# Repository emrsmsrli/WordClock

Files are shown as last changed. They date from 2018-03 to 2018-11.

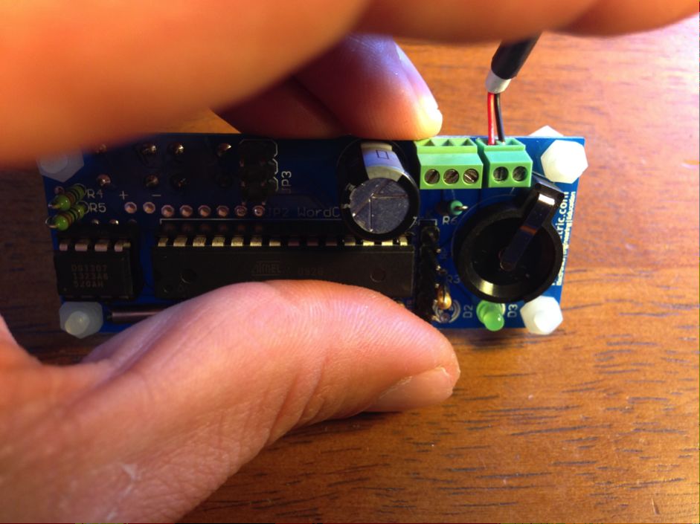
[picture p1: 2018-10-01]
etc/img/circuit/16.jpg

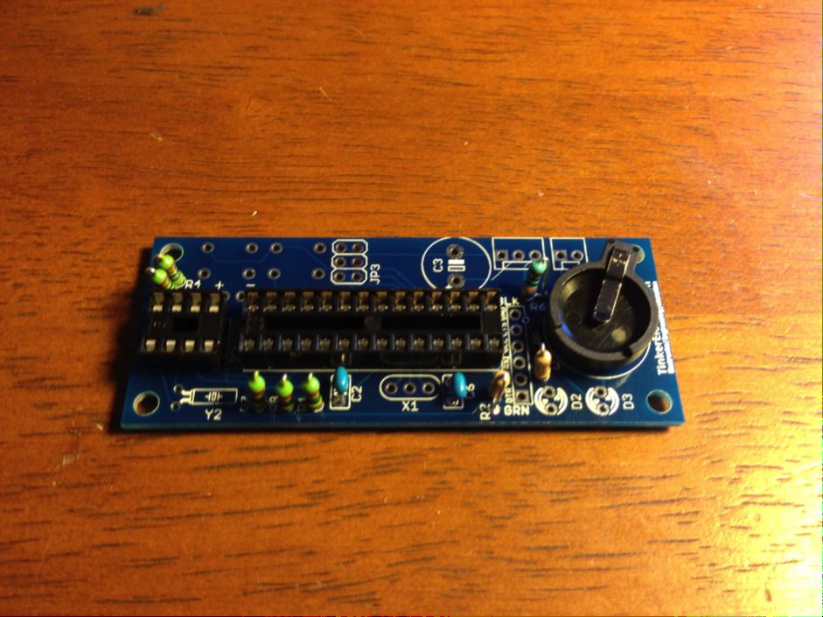
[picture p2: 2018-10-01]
etc/img/circuit/2.jpg

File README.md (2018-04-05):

# WORD CLOCK ARDUINO

The code in this repository is a heavily modified version of 
[Tinker's Word Clock code](http://www.instructables.com/id/Tinkers-Word-Clock-REVISITED-NOW-110-More-AWESOME-/). 
And uses a modified version of [OneButton](https://github.com/mathertel/OneButton) library.

## TODO
- [x] Add second support alongside of minutes and hours
- [x] Make the leds fade-in and -out when a change in time or color happens
- [x] Use external interrupts to count button clicks so we can increment both hour and minute with a single button
- [x] Implement smoothstep interpolation to led animations
- [x] Implement night mode, where overall led intensity is 0.125 instead of 1.0
- [x] Implement happy birthday mode
- [x] Add documentation

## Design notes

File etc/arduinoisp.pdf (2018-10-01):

Arduino Uno as an ISP programmer

Programming a Target AVR using Arduino Uno board loaded with

ArduinoISP

(April 21, 2015, author: B. Lazar) Arduino Uno + ArduinoISP form an ordinary ISP programmer that is used by avrdude to program various 8 bit AVRs with any kind of hex file. No bootloader is needed, no hardware removal from Arduino Uno is necessary

It may happen that you have an Arduino Uno that you bought, played a bit with it and now you want to move further, to build your own board, which can be just a simple AVR microcontroller + an oscillator + a LED, but you do not have an ISP programmer.

In reality, Arduino Uno is everything you need to program a large variety of AVRs. You just have to follow the four steps described below:
1) Open Arduino 1.0.1 and upload ArduinoISP to Arduino Uno.
2) Connect the ISP pins of Arduino Uno to the Target AVR as indicated in the Fig.1.
3) Write your source code, compile it and generate the hex file.
4) Use avrdude command lines to upload the hex file into the Target AVR.

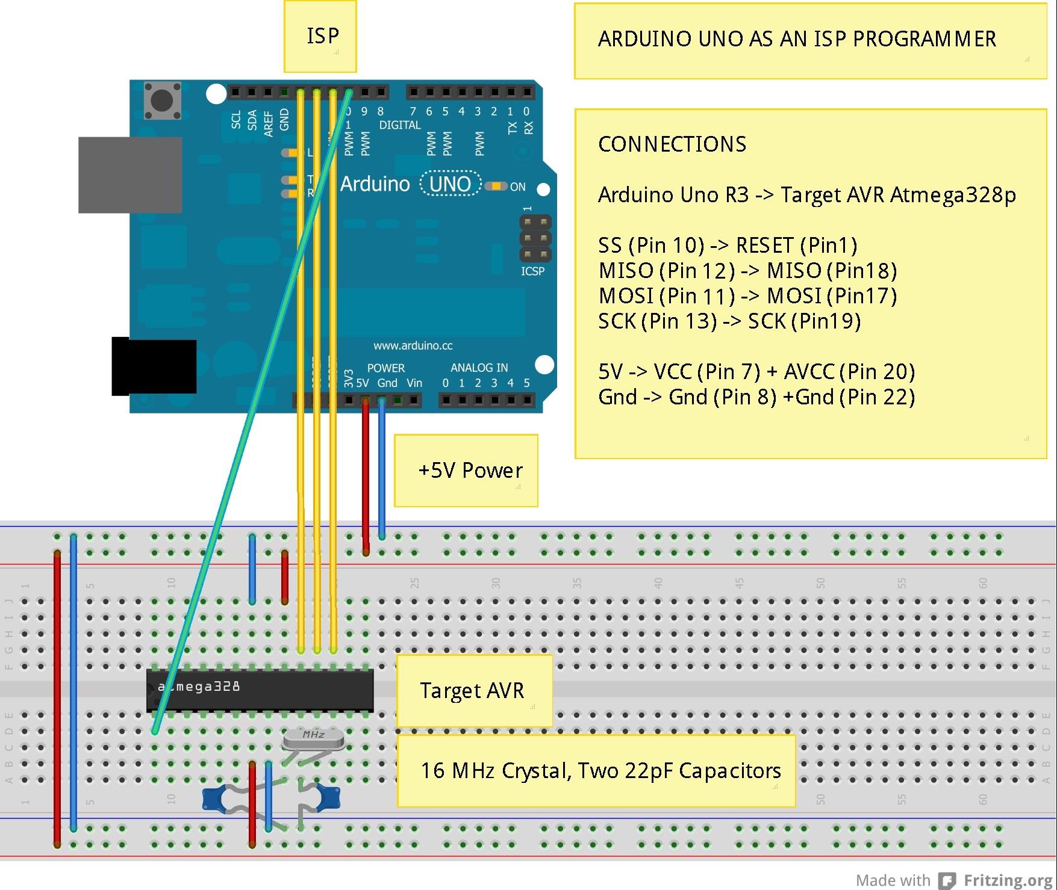
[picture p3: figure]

Fig. 1

Each of the four steps explained in detail:

(1) Open Arduino 1.0.1 and upload ArduinoISP to Arduino Uno
Start Arduino 1.0.1, go to Files->Examples and open ArduinoISP. Then from Tools->Board select Arduino Uno, from Tools->Programmer select AVR ISP or Arduino as ISP. Access Tools->Serial Port and write down the name of the port (ex. COM3) which is needed for avrdude.

Finally, press Files->Upload to load ArduinoISP to Arduino Uno. This operation transforms Arduino Uno into an ISP programmer.

(2) Connect the ISP pins of Arduino Uno to the Target AVR as indicated in Fig.1
It is extremely important to make sure that the ISP pins of Arduino Uno are connected to the Target AVR like this:
Arduino Uno | Target AVR (ex. Atmega328p)
SS | RESET
MOSI | MOSI
MISO | MISO
SCK | SCK

Frequent wiring mistakes are Arduino Uno(SS) -> Target AVR(SS) and Arduino Uno(RESET) -> Target AVR(RESET).

As a note: The crystal and its two capacitors have to be as close to XTAL1, XTAL2 pins of the Target AVR as possible (like in Fig. 1). If you position them in a different configuration, far from the processor, running wires between capacitors, crystal and the AVR, the newly formed oscillator can refuse to work and avrdude will throw the error “Invalid device signature” when you try to program the microcontroller.

(3) Write your source code, compile it and generate the hex file
In Arduino 1.0.1->Files->Preferences check Show verbose output during compilation. This will display a lot of information, when the code is compiled, including the location of the hex file.

Go to File->Examples->01.Basics and load Blink example. This will be considered as your source code.

Go to Sketch menu and press Verify/Compile.

When the compilation completes search in the lower side of the screen the path of the generated Blink hex file. It looks like this one:

C:\Users\Victor\AppData\Local\Temp\build1325897986179133197.tmp\Blink.cpp.hex

Select it with the mouse and press Ctrl-C followed by a Paste in Notepad, for instance. You will need the path for avrdude.

REMARK: The hex file can be generated with any IDE you like, not necessarily using Arduino 1.0.1. You can write your code in: BASCOM, CodeVision, AVR Studio, IAR which, in most cases, are far better choices than Arduino 1.0.1.

ATTENTION! If you use Arduino 1.0.1 to generate a hex file, you have to select the right board/processor from Tools->Board. For example, you simply can not compile the Blink Led code for Arduino Uno

(Atmega328p) and expect it to work on a target Atmega32 microcontroller. Also, even if, your target chip on the breadboard is an Atmega328p DIL28, you have to take into account that pin 13 of Arduino Uno (the one that drives the led) corresponds to pin 19 (SCK) on your target Atmega328p microcontroller.
AS A CONCLUSION: Arduino 1.0.1 works well for compiling code written for the boards in its list.
For anything else, different boards or stand alone AVRs, it is highly indicated to use a general purpose IDE, not Arduino 1.0.1.
(4) Use avrdude command lines to upload the hex file into the Target AVR
Avrdude comes bundled with WinAVR, a software that is free and can be found on the internet.
Locate avrdude inside WinAVR, start the Windows standard application Command Prompt and launch avrdude from within Command Prompt.
A better choice would be to use a software, similar to Command Prompt but much easy to use, called PowerCmd because it allows you to save and copy-paste the long avrdude command lines, with many options and complicated paths to hex files, necessary to program an AVR (see the example).

At this moment, it is supposed that Arduino Uno is already loaded with ArduinoISP, connected to the PC with an USB cable and all wires, between the Target AVR and Arduino Uno acting as an ISP programmer, are in their place as in Fig. 1.

For the example that follows, the Target AVR is chosen to be an Atmega328p already set to run at 16 MHz.

EXAMPLE:

Launch PowerCmd (or Command Prompt) and copy this line:

c:\>avrdude -P COM3 -b 19200 -c avrisp -p m328p –n

in one of its command windows.

If your AVR is different then change the option -p m328p to -p … corresponding to your microcontroller. Most likely you do not have to modify the other options. (Note: The command c:\>avrdude -? will display a list with explanations regarding the meaning of the switches: –P, -b, -c, -p, -n and many others.)

Press Enter.

Avrdude should display the message:

c:\>avrdude -P COM3 -b 19200 -c avrisp -p m328p -n
avrdude: AVR device initialized and ready to accept instructions
Reading | ################################################## | 100% 0.14s
avrdude: Device signature = 0x1e950f
avrdude: safemode: Fuses OK
avrdude done. Thank you.

telling you that the Target AVR is accessible and can be programmed. (-n option instructs avrdude to make no modification inside the Target AVR).

You can program now the Target AVR with the Blink.cpp.hex file, generated at point (3), by copying the avrdude command, highlighted in red (see below), in PowerCmd and pressing Enter.
Do not forget to change the path to the hex file (the string of characters between “”) according to the settings in your computer. The rest of the command line, including the final “:i” will likely remain unchanged.

c:\>avrdude -P COM3 -b 19200 -c avrisp -p m328p -u -U flash:w:"C:\Users\Victor\AppData\Local\Temp\build1325897986179133197.tmp\Blink. cpp.hex":i

avrdude: AVR device initialized and ready to accept instructions

Reading | ################################################## | 100% 0.16s

avrdude: Device signature = 0x1e950f
avrdude: NOTE: FLASH memory has been specified, an erase cycle will be performed To disable this feature, specify the -D option. avrdude: erasing chip
avrdude: reading input file "C:\Users\Victor\AppData\Local\Temp\build1325897986179133197.tmp\Blink.cpp.hex" avrdude: writing flash (1084 bytes):
Writing | ################################################## | 100% 1.76s

avrdude: 1084 bytes of flash written
avrdude: verifying flash memory against C:\Users\Victor\AppData\Local\Temp\build1325897986179133197.tmp\Blink.cpp.hex: avrdude: load data flash data from input file C:\Users\Victor\AppData\Local\Temp\build1325897986179133197.tmp\Blink.cpp.hex: avrdude: input file
C:\Users\Victor\AppData\Local\Temp\build1325897986179133197.tmp\Blink.cpp.hex contains 1084 bytes
avrdude: reading on-chip flash data:
Reading | ################################################## | 100% 1.31s

avrdude: verifying ...
avrdude: 1084 bytes of flash verified

avrdude done. Thank you.

Success! At this moment your Target AVR is programmed and ready to execute the code.

Most common errors you may get from avrdude:

1) c:\>avrdude -P COM3 -b 19200 -c avrisp -p m328p -n
avrdude: ser_open(): can't open device "\\.\COM3": The system cannot find the file specified.

Reason: The USB connection between the PC and Arduino Uno is not good. If the connection is good but the error still keeps coming press the Reset button of Arduino Uno.

2) c:\>avrdude -P COM3 -b 19200 -c avrisp -p m328p -n
avrdude: ser_open(): can't open device "\\.\COM3": Access is denied.

Reason: Another application that uses COM3 port, likely a Serial Monitor, is running. Close it.

3) c:\>c:\>avrdude -P COM3 -b 19200 -c avrisp -p m328p -n
Access is denied.

Reason: c drive appears twice: “c:\>c:\>”.

4) c:\>avrdude -P COM3 -b 19200 -c avrisp -p m328p -n
avrdude: stk500_program_enable(): protocol error, expect=0x14, resp=0x50 avrdude: initialization failed, rc=-1
Double check connections and try again, or use -F to override this check.
avrdude: stk500_disable(): protocol error, expect=0x14, resp=0x51 avrdude done. Thank you.

Reason: The Target AVR is not powered or does not exist.
This message is also useful for testing, before connecting any Target AVR, that Arduino Uno + ArduinoISP work as an ISP programmer and the connection to the PC is proper.
5) c:\>avrdude -P COM3 -b 19200 -c avrisp -p m328p -n
avrdude: stk500_getsync(): not in sync: resp=0xf0
avrdude done. Thank you.

Reason: Arduino Uno needs a Reset.

6) c:\>avrdude -P COM3 -b 19200 -c avrisp -p m328p -n
avrdude: AVR device initialized and ready to accept instructions
Reading | ################################################## | 100% 0.14s
avrdude: Device signature = 0xffffff (Device signature = 0x000000)
avrdude: Yikes! Invalid device signature.
Double check connections and try again, or use -F to override this check.

Reasons:
a) ISP connections (SS, MOSI, MISO, SCK) -> (RESET, MOSI, MISO, SCK), between Arduino Uno and the Target AVR, are not good, wrong wiring.
b) The AVR oscillator (external) does not work.

List of commonly used AVRs and how they should be connected to an Arduino

Uno, for programming

If you do not use an Atmega328p target then you should adapt the wiring in Fig. 1 according to your specific target AVR (ex. Attiny13, 84, 85, Atmega8, etc.).

Attiny13 | Uno -> pin Attiny13

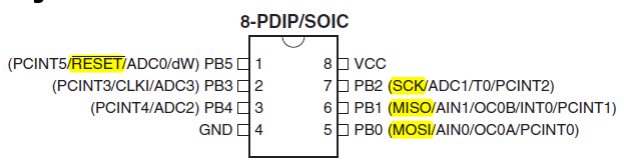
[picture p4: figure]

| SS -> 1 MOSI -> 5 MISO -> 6 SCK -> 7

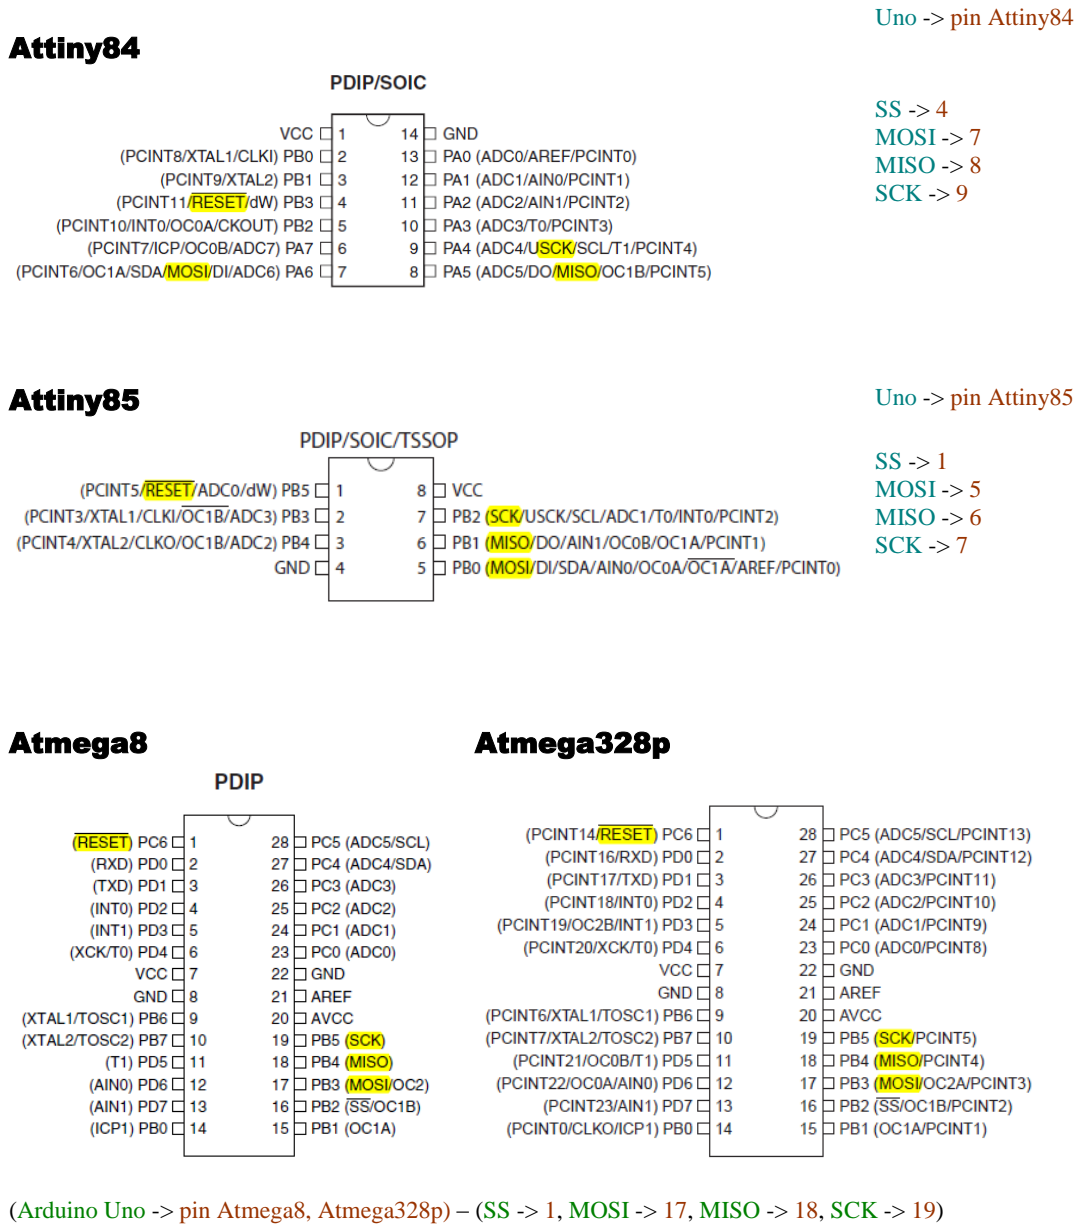
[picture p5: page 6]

Attiny84 | Uno -> pin Attiny84
| SS -> 4 MOSI -> 7 MISO -> 8 SCK -> 9
Attiny85 | Uno -> pin Attiny85
| SS -> 1 MOSI -> 5 MISO -> 6 SCK -> 7

Atmega8

Atmega328p

(Arduino Uno -> pin Atmega8, Atmega328p) – (SS -> 1, MOSI -> 17, MISO -> 18, SCK -> 19)

Atmega32U4

Uno

>Atmega32U4

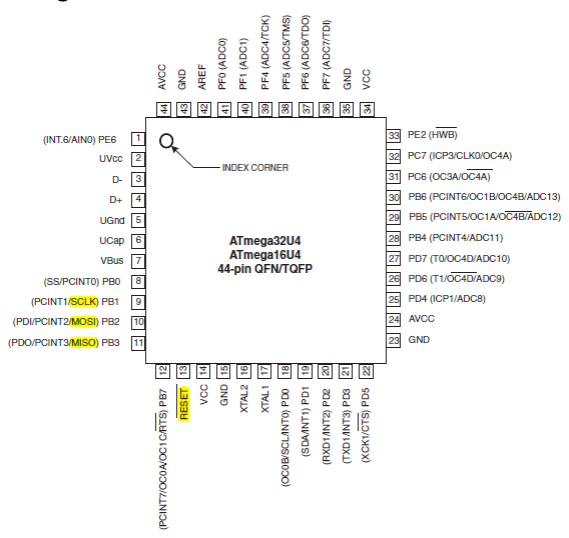
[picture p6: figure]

SS

->

1

3
MOSI

-> 10
MISO

-> 11
SCK

->

9

Atmega32 | Uno -> pin Atmega32

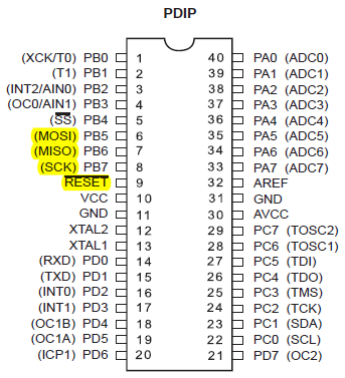
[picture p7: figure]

| SS -> 9 MOSI -> 6 MISO -> 7 SCK -> 8

Last update: July 3, 2016.

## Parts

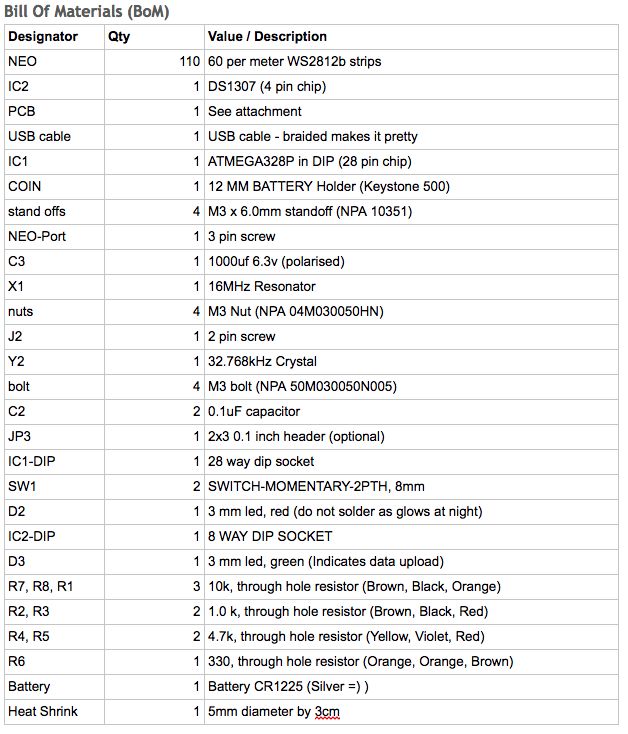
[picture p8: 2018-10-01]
etc/materials.jpg

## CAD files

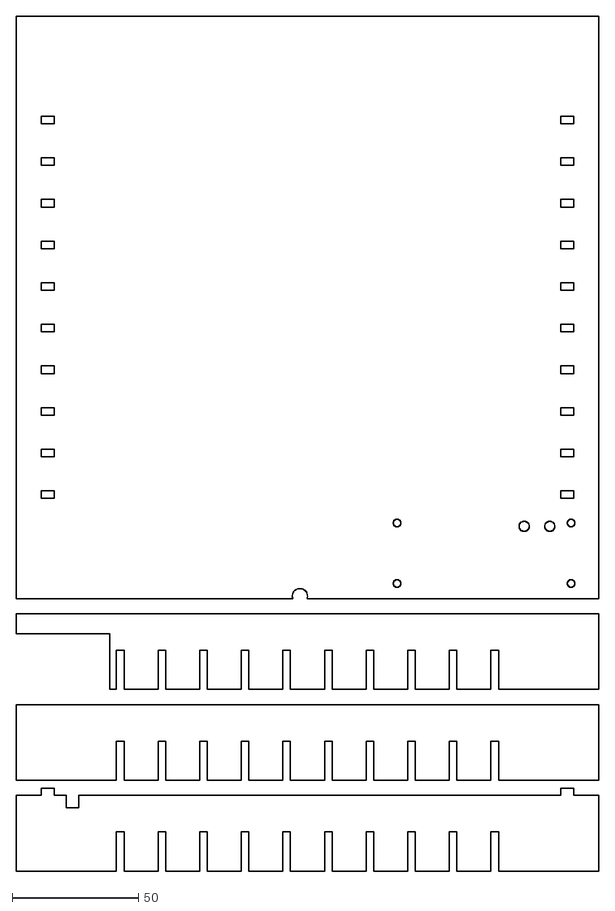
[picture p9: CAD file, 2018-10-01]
etc/backface/final/slat_output_m.dxf
231.0 x 339.0

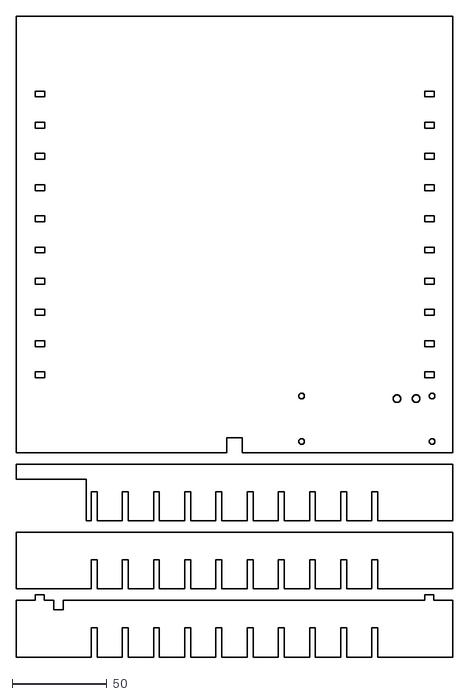
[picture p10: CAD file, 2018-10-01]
etc/backface/slat_output.dxf
231.0 x 339.0

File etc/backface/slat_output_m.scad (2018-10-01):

$fn=50;
materialWidth = 2.9;

numberOfSlots = 10;
spacingOfSlots = 16.5; //Absolute, between centres, this is the LED spacing

cableSlot = 5; // Width/height of cable slot

shortLength = 37;
shortHeight = 22;

slatLength = 231; //Overall length
slatHeight = 30; //Overall height

backPlaneLength = 231;
lockingPinWidth = 5;
lockingPinRafterInset = 10;

slotWidth = materialWidth+0.1; //Slot plus a little for fitting
slotHeight = slatHeight/2+0.5; //height plus a little for fitting


spaceBetweenRepeats = 6; //When you repeat them

shiftBy = (slatLength-((numberOfSlots-1)*spacingOfSlots+slotWidth))/2;


//slatLength/2 -
//        (numberOfSlots*(spacingOfSlots+slotWidth))/2 + spacingOfSlots/2;

// counts: 1, 7, 7, 11

    
for (i = [0:0]){
    translate([0,i*(slatHeight+spaceBetweenRepeats)])
        rafter(cableHole = "yes", lockingPin ="yes");
    }

for (i = [1:1]){
    translate([0,i*(slatHeight+spaceBetweenRepeats)])
        rafter(cableHole = "no", short ="no");
    }

for (i = [2:2]){
    translate([0,i*(slatHeight+spaceBetweenRepeats)])
        rafter(cableHole = "no", short ="yes");
    }


    
for (i = [3:3]){
    translate([0,i*(slatHeight+spaceBetweenRepeats)])
        translate([0,0]){
            backPlate();}
    }    
    
    


module rafter (){
    //one of them
            if(lockingPin=="yes"){
            translate([lockingPinRafterInset,slatHeight]){
                square(size = [lockingPinWidth,materialWidth],center=false);
            }
            translate([slatLength-lockingPinRafterInset-lockingPinWidth,slatHeight]){
                square(size = [lockingPinWidth,materialWidth],center=false);
            }
        }
    difference() {
        square(thickness = materialWidth, size = [slatLength,slatHeight],center=false); //main slat
        if(cableHole=="yes"){
            //power cable
            translate([shiftBy/2
                    ,slatHeight-cableSlot])
            square(size = [cableSlot,cableSlot],center=false);}


            //short
        if(short=="yes"){
            square(size = [shortLength,shortHeight],center=false);}
        

        
        //Move the slots to centre them
        translate([shiftBy
                ,0,0])
            //square(size = [5,5], center = false);
        
           for (i = [0:numberOfSlots-1]){
                translate([i*(spacingOfSlots),0])
                square(size = [slotWidth,slotHeight],center=false); //removed slat
        }
        
    }
}



module backPlate(){
    difference() {
        square(thickness = materialWidth, size = [backPlaneLength,backPlaneLength],center=false); 
        translate([backPlaneLength-80-3,3]){ //indent the pcb from the edge by this much
            circuitBoard();
        }
        translate([backPlaneLength/2 - 6/2,1]){
                circle(3);
                //square(size=[6,6]);
        }
        
        translate([0,((backPlaneLength-((numberOfSlots-1)*spacingOfSlots+slotWidth))/2)]){
            for (i = [0:numberOfSlots-1]){
                translate([0,i*spacingOfSlots]){
                    translate([lockingPinRafterInset+(backPlaneLength-slatLength)/2,0]){ //left side
                        square([lockingPinWidth+0.1,materialWidth+0.1]); //slot for positioning
                    }
                    translate([backPlaneLength-lockingPinWidth-lockingPinRafterInset-(backPlaneLength-slatLength)/2,0]){ //right side
                        square([lockingPinWidth+0.1,materialWidth+0.1]); //slot for positioning
                    
                    }
                }
            }
        }
        
        
    }
}


module circuitBoard(){
            //button 1
            standOffHoleSize = 3/2; //radius
            buttonHoleSize = 4/2;//radius

            translate([75-11.43,25.65]){ //80-18.221,35-28.656
                circle(buttonHoleSize);
            }
            //button 2
            translate([75-21.59,25.65]){ //80-38.481,35-28.656
                circle(buttonHoleSize);
            }
            
            //standoffs x4
             translate([3,3]){
                circle(standOffHoleSize);
            }       
             translate([3,27]){
                circle(standOffHoleSize);
            }  
            translate([72,3]){
                circle(standOffHoleSize);
            }  
            translate([72,27]){
                circle(standOffHoleSize);
            } 

}

module pcbAdapter(){
    difference(){
        circle(6/2);
        circle(4/2);
    }
}

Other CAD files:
etc/backface/slat_output.scad

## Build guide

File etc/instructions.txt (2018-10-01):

Three major components go into building this clock:

The Electrical - this keeps track of the time, changes the colour and makes it glow all pretty. This is made of the ‘PCB’ (Printed Circuit Board), microcontroller and power via USB.
The Mechanical - This is responsible for its structure and preventing the light seeping into other letters. Its mainly made of the ‘baffle’ and a backing plate.
The Face - To get the face done nicely we use a vinyl sticker with frosting. Out of all the methods I’ve found this to work the best. The face is responsible for the letters appearing crisp and readable.
Next, we collect all the parts!

Gather the following parts:

Mechanical:

Acrylic for internal structure - 2mm black opaque acrylic sheet 16.5 inches (420mm) by 28.3 inches (720mm). This will need to be laser cut later. There are a variety of local laser cutting workshops available to do this.
Ikea Ribba frame (9inch / 23cm square), either black or white http://www.ikea.com/us/en/catalog/products/60078034/#/00078032 This will be our outside frame.
Electrical:
The following parts below are needed. Note: the lithium battery is not normally included due to flight restrictions.

Bill Of Materials (BoM) (see attached image)

PCB and Schematic: (see attached images)

-Attached is the Eagle schematic and board. As well as the GERBER files needed to get the board produced at a PCB house.

Face: The face is to be cut out of vinyl adhesive. An additional ‘frosting’ layer is added to diffuse the light. (see attachment)

Code: Code is attached (*.ino) this can be uploaded using the Arduino uploader.
You will need:

Parts:

PCB and all electronic components listed in the Bill of Materials (BoM)
Tools:

Soldering Iron
Safety Glasses
Solder
Side Cutters
Assembling the main Printed Circuit Board (PCB)

Following the BoM, solder each of the components.

It is best to start with the IC holders (IC1-DIP, IC2-DIP). This ensures it is all flat. Note the notch and align to this.
Resistors are the next step. Identify them using the colour band codes listed in the BoM.
Install capacitors C1 and C2
Solder the three pin resonator. There is no polarisation/wrong way of putting this.
Install the 32kHz crystal at Y2. No polarisation. Leave enough leg space for bending.
Optional: Green LED D3 can now be installed. This indicates data transfer when uploading code.
D2 Red LED can be skipped as it might shine through at night time creating an unwanted glow.
Screw terminals can now be installed. Note that the opening must face the outside of the board.
JP3 and the FTDI programming header are optional
C3 Large capacitor has a polarisation. Note the long and short leg, also the white line (opposite side then photographed) The negative (short+white band) goes on the outer edge, the diagram also matches (colored in bar on the silk screen).
The two buttons are to be installed on the back side. This is so they poke through the back holes.
You can now install the ICs. Nore the notch that must line up. In this picture the notches are far left on each.
Now we can add the standoffs
Place the post though the bottom and nut over the top. It works best if you hold the nut and screw the post into it from the under side.
Posts are now complete.
Cut the USB cable on the mini/micro side as we are keeping the large USB plug to power the device.
Pull back the woven braid and expose the wires inside.
Discard the white and green wires as we only need red (positive) and black (negative)
Add heat shrink as to prevent the braid from running away
Connect the power cable to the main PCB as seen here. We are now done with the PCB for now.
Please see the corrections if you have Version 1.2 below
Fixes in Version 1.2

Fix 1: Jumper JP3 pin and switch pin shown below. This corrects power only being routed to a portion of the board. Best to do this after all soldering so the switch is unobstructed.
Fix 2: Note that Version 1.2 incorrectly labeled the Light port. Light strip labeling is as below, looking from the top, Left to Right: Negative (Black), Positive (Red), Data (Yellow)
Attached are the items for laser cutting the baffle and back plate. There is an SCAD model allowing you to change the size of the clock. Also an SVG with one of each item.

After laser cutting the parts you will now have:

10 Full beams
10 Beams with a notch
1 Backplate
The job now is to line up the RGB light strips onto the back panel.

Place the panel down so that the centre notch is at the bottom and that the text is not showing.

Let us start with the end in mind

This is what we will end up with.

NOTE: The arrows indicate the direction of data and must line up with the arrows on the strips

NOTE: Note how the strips fall with respect to the notches on the side. The first one is above the top notch.

Let’s look at the strip closely before we start.

Each LED strip has three contacts.

GND - Ground,

D - Data (In/Out) and

+5V - 5 volt power

And little arrows pointing the direction. It is important that the arrows follow that of the previous picture. The data exits the PCB bottom left and snakes all the way to the top. It is our job now to A) stick the strips down correctly and then B) connect the outputs of one to the correct imports of the next strip. So let’s begin.

Starting at the top, hold a full beam over the notches as shown here:

Now you can start to see the alignment of the leds. Starting at the top, the first let strip needs to have the arrow point (direction of data) LEFT, this is important. The first top strip is placed ABOVE the holes in the board. Compare to the main image to see that this is correct.

Using the horizontal bar and its notches to line up the leds, make it so that when the baffle is in place that the leds fall in the middle.

We will end up with this seen above.

Continue to add a row at a time, making sure the notches line up with the gold pads. The notches are where the vertical struts will go.

Continue this process until all 10 rows are placed. Note that there is no LEDs on the bottom row. This is where we keep the electronics.

Before we can assemble the baffle we will need to solder the LED strips together in a particular fashion.

Data to Data, Power to Power, Ground to Ground. You will need to solder in such a way that the notch in the full beam allows the wires to pass through without too much fuss. Use the beam to test as you go. This part takes some time so take breaks. We are getting there!

We can now screw down the PCB. The buttons will become available on the back.

Now solder a short 10 cm length to the very last one. This is where data and power will enter.

You will now need to add a battery to the system. This is required else the Real Time Clock (RTC) will give spurious outputs.

At this point we can test the whole system. Plug in the USB cable. The top left lights (positions 1,2, 4,5) should light up (IT IS). If they don’t trace back the system. Since it works as a string all previous segments must be ok. When this is proven, and you can adjust the lights from the buttons at the back, then we can move forward.
Remove the paper from the baffles, take care when removing the paper not to break any though this is an internal part and will not effect final performance. Now we can add all the horizontal baffles. Align the notch with the wire and then click into the base.

The vertical baffles can now be added. Note that the cut out section goes to the bottom to allow space for the PCB.

Holding the USB cable at the notch to exit this is a good point to add hot glue to hold it in pace.

Closing it up:

You can now place the face on top of the baffle, note the PCB is the bottom left.

Slide the frame over the top, close the tabs and you are done. This may be right so be patient.

Congratulations on your magnificent build.

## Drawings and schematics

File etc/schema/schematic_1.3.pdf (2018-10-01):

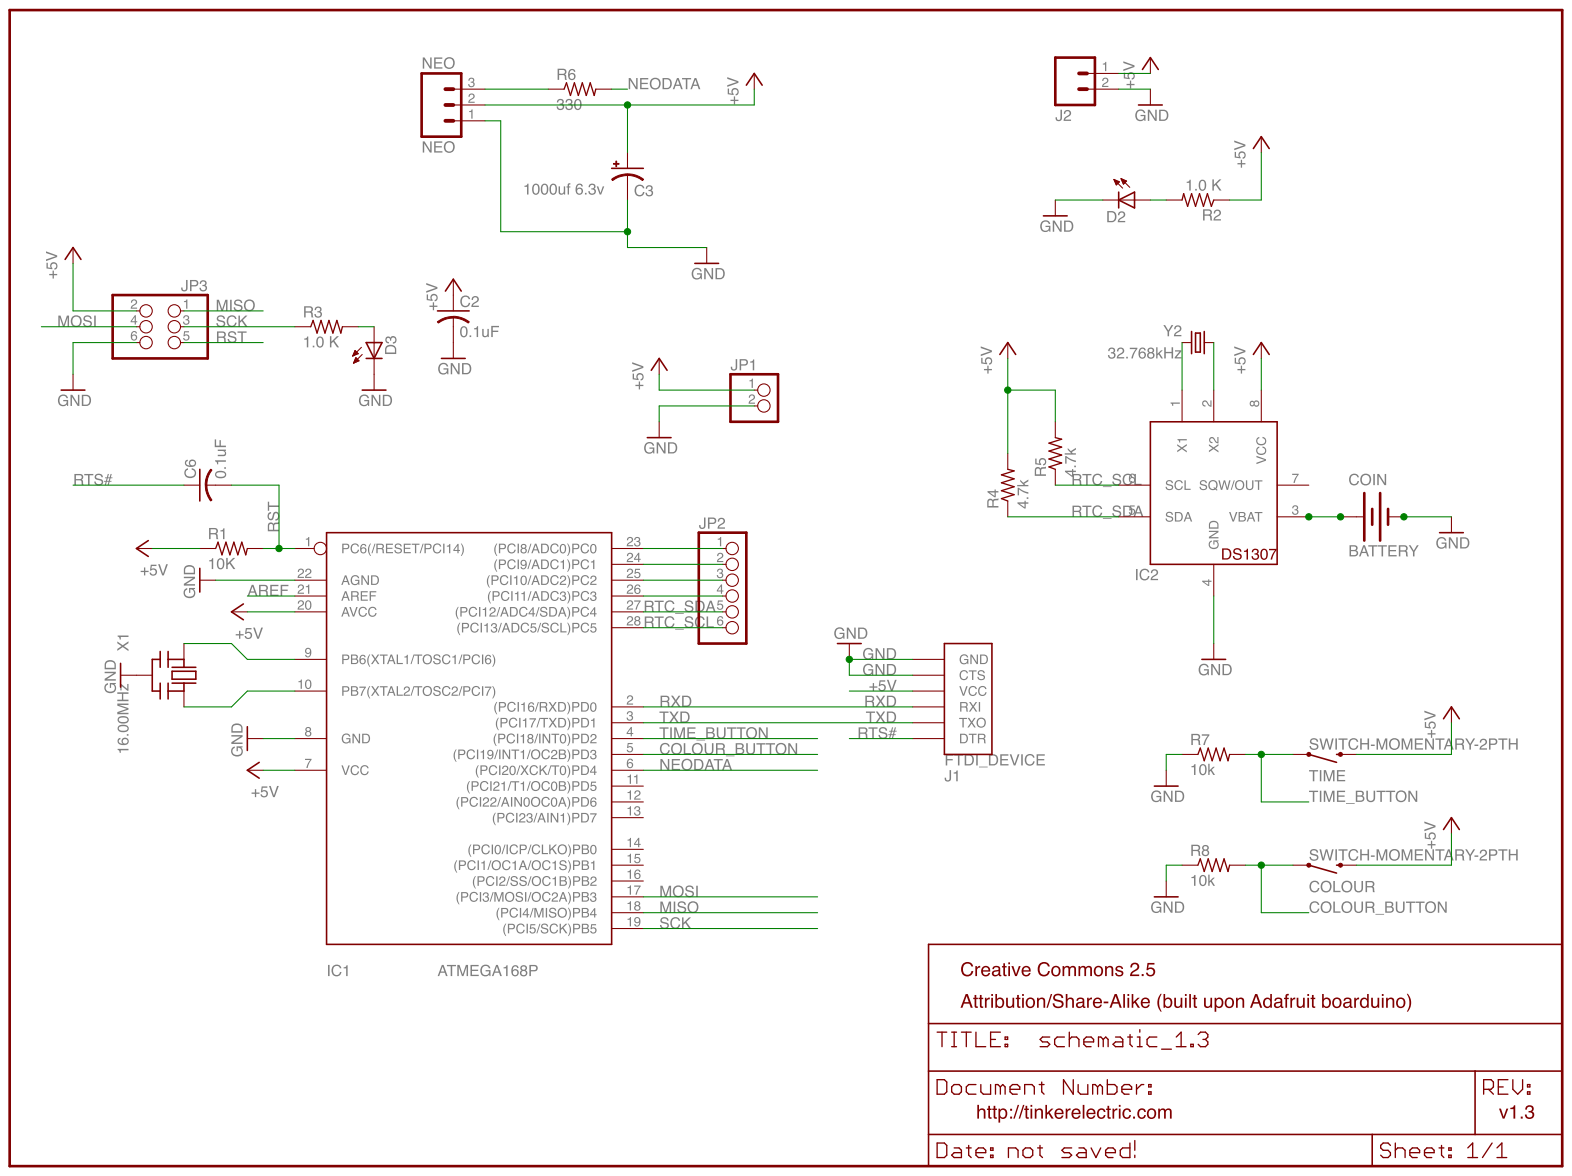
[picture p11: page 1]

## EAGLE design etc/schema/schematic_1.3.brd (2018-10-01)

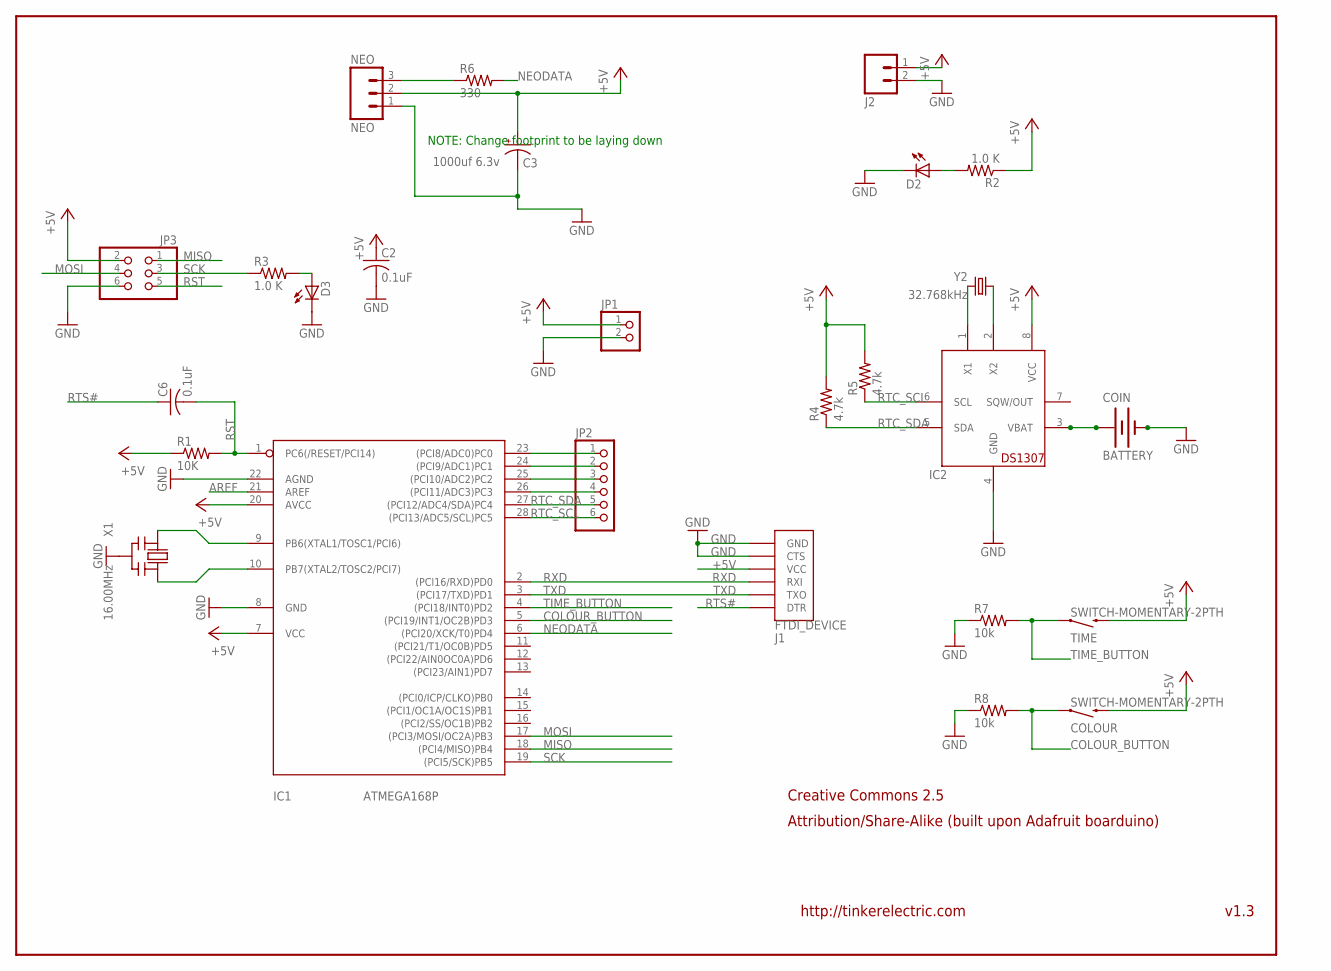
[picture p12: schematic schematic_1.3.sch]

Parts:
C2, C6: 0.1uF; C025-025X050
C3: 1000uf 6.3v; E5-10,5
COIN: BATTERY; BATTCOM_12MM
COLOUR: SWITCH-MOMENTARY-2PTH; TACTILE-PTH
D2: LED3MM
D3: Green; LED3MM
IC1: ATMEGA168P; DIL28/3
IC2: DS1307; DIL08
J1: FTDI_DEVICE; FTDI_DEVICE_SIDE
J2: M02POLAR; MOLEX-1X2
JP1: PINHD-1X2CB; 1X02-CB
JP2: PINHD-1X6CB; 1X06-CLEANBIG
JP3: PINHD-2X3; 2X03
NEO: NEO; MOLEX-1X3
R1: 10K; 0204V
R2, R3: 1.0 K; 0204V
R4, R5: 4.7k; 0204V
R6: 330; 0204V
R7, R8: 10k; 0204V
TIME: SWITCH-MOMENTARY-2PTH; TACTILE-PTH
X1: 16.00MHz; CERM_OSC
Y2: 32.768kHz; TC26HEZ

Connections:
+5V: C2.1, C3.+, COLOUR.3 (2), IC1.7 (VCC), IC1.20 (AVCC), IC2.8 (VCC), J1.P$4 (VCC), J2.1, JP1.1, JP3.2, NEO.2, R1.1, R2.1, R4.2, R5.2, TIME.3 (2)
AREF: IC1.21 (AREF)
COLOUR_BUTTON: COLOUR.1, IC1.5 ((PCI19/INT1/OC2B)PD3), R8.2
GND: C2.2, C3.-, COIN.-, D2.K (C), D3.K (C), IC1.8 (GND), IC1.22 (AGND), IC2.4 (GND), J1.P$5 (CTS), J1.P$6 (GND), J2.2, JP1.2, JP3.6, NEO.1, R7.1, R8.1, X1.P$2 (GND)
MISO: IC1.18 ((PCI4/MISO)PB4), JP3.1
MOSI: IC1.17 ((PCI3/MOSI/OC2A)PB3), JP3.4
unnamed: IC1.9 (PB6(XTAL1/TOSC1/PCI6)), X1.P$1 (IN)
unnamed: IC1.10 (PB7(XTAL2/TOSC2/PCI7)), X1.P$3 (OUT)
unnamed: D2.A, R2.2
unnamed: D3.A, R3.2
unnamed: NEO.3, R6.1
unnamed: IC2.2 (X2), Y2.1
unnamed: IC2.1 (X1), Y2.2
unnamed: COIN.+, IC2.3 (VBAT)
unnamed: IC1.23 ((PCI8/ADC0)PC0), JP2.1
unnamed: IC1.24 ((PCI9/ADC1)PC1), JP2.2
unnamed: IC1.25 ((PCI10/ADC2)PC2), JP2.3
unnamed: IC1.26 ((PCI11/ADC3)PC3), JP2.4
NEODATA: IC1.6 ((PCI20/XCK/T0)PD4), R6.2
RST: C6.2, IC1.1 (PC6(/RESET/PCI14)), JP3.5, R1.2
RTC_SCL: IC1.28 ((PCI13/ADC5/SCL)PC5), IC2.6 (SCL), JP2.6, R5.1
RTC_SDA: IC1.27 ((PCI12/ADC4/SDA)PC4), IC2.5 (SDA), JP2.5, R4.1
RTS#: C6.1, J1.P$1 (DTR)
RXD: IC1.2 ((PCI16/RXD)PD0), J1.P$3 (RXI)
SCK: IC1.19 ((PCI5/SCK)PB5), JP3.3, R3.1
TIME_BUTTON: IC1.4 ((PCI18/INT0)PD2), R7.2, TIME.1
TXD: IC1.3 ((PCI17/TXD)PD1), J1.P$2 (TXO)

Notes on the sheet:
v1.3
http://tinkerelectric.com
Creative Commons 2.5
Attribution/Share-Alike (built upon Adafruit boarduino)
NOTE: Change footprint to be laying down

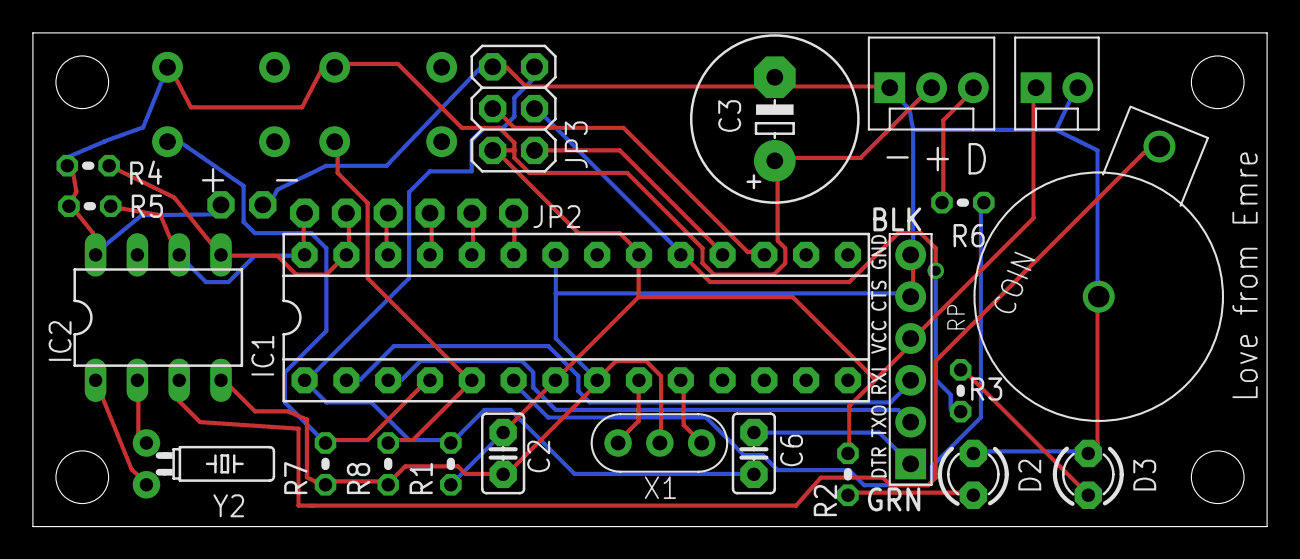
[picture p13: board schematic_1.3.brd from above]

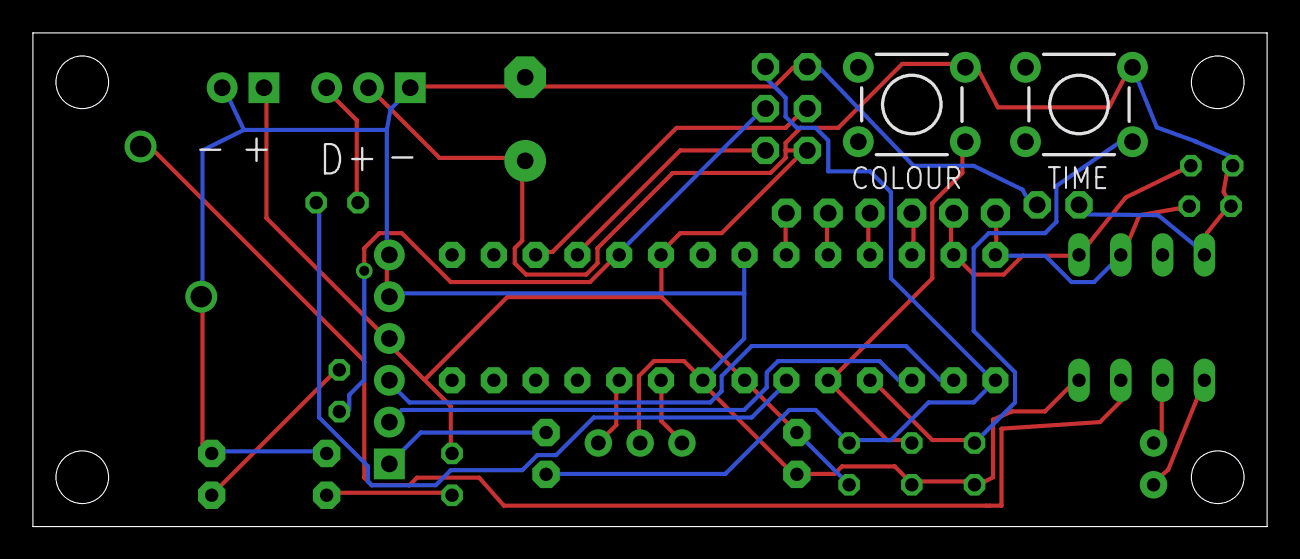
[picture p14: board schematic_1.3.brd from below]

Board: 2 copper layers, 75.0 x 30.0 mm, 26 parts (2 on the bottom side), 26 nets.

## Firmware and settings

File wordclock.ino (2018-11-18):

#include "wordclock.hpp"
#include "EEPROM.h"

RTC_DS1307 rtc;
DateTime time;
TimeSpan ONE_SEC(0, 0, 0, 1);
TimeSpan ONE_MIN(0, 0, 1, 0);
TimeSpan ONE_HOUR(0, 1, 0, 0);

Button *TIME_BUTTON;
Button *COLOR_BUTTON;

LedArray IT(105, 107);
LedArray IS(108, 110);
LedArray O_OCLOCK(6, 12);
LedArray O_PAST(61, 65);
LedArray O_TO(72, 74);

LedArray M_NONE(0, 0);
LedArray M_5(90, 94);
LedArray M_10(75, 78);
LedArray M_15(97, 104);
LedArray M_20(83, 89);
LedArray M_25(83, 94);
LedArray M_30(79, 83);

/// Array of LedArrays for hours.
LedArray H[] = {
        LedArray(28, 34)     // H_12
        LedArray(58, 61),    // H_1
        LedArray(55, 58),    // H_2
        LedArray(50, 55),    // H_3
        LedArray(39, 43),    // H_4
        LedArray(43, 47),    // H_5
        LedArray(47, 50),    // H_6
        LedArray(66, 71),    // H_7
        LedArray(17, 22),    // H_8
        LedArray(35, 39),    // H_9
        LedArray(14, 17),    // H_10
        LedArray(22, 28),    // H_11
};

uint8_t seconds_led = 1;
LedArray minute_led = M_NONE;
LedArray hour_led = H[0];
LedArray oclock_led = O_OCLOCK;

uint8_t last_second_led = seconds_led;
LedArray last_minute_led = minute_led;
LedArray last_hour_led = hour_led;
LedArray last_oclock_led = oclock_led;

/// The brightness multiplier variable.
uint8_t brightness = BRIGHTNESS_HIGH;

/// Index of the current color of the leds.
uint8_t led_color_idx = 0;

/// Array of colors. Change \c N_COLORS in wordclock.h if
/// this array changes.
uint32_t colors[] = {
        pixels.Color(247, 139, 15),     // orange
        pixels.Color(127, 127, 0),      // yellow
        pixels.Color(127, 0, 127),    // magenta
        pixels.Color(0, 127, 127),    // cyan
        pixels.Color(0, 0, 255),    // blue
        pixels.Color(0, 255, 0),      // green
        pixels.Color(255, 0, 0)       // red
};

void delay_short() {
    delayMicroseconds(DELAY_SHORT_US);
}

uint32_t current_color() {
    float brightness_mult = brightness / static_cast<float>(BRIGHTNESS_HIGH);
    color c = extract_color(colors[led_color_idx]);

    return pixels.Color(
            static_cast<uint8_t>(c.r * brightness_mult),
            static_cast<uint8_t>(c.g * brightness_mult),
            static_cast<uint8_t>(c.b * brightness_mult)
    );
}

uint8_t smooth_step(uint8_t i, uint8_t N, uint8_t min, uint8_t max) {
    float v = SMOOTH_STEP(i / static_cast<float>(N));
    return static_cast<uint8_t>((max * v) + (min * (1 - v)));
}

color extract_color(uint32_t c) {
    color clr;
    clr.r = static_cast<uint8_t>(c >> 16);
    clr.g = static_cast<uint8_t>(c >> 8 & 0xFF);
    clr.b = static_cast<uint8_t>(c & 0xFF);
    return clr;
}

uint32_t shift_color(uint8_t i, uint8_t N, uint32_t old_color, uint32_t new_color) {
    color c_old = extract_color(old_color);
    color c_new = extract_color(new_color);
    return pixels.Color(smooth_step(i, N, c_old.r, c_new.r),
                        smooth_step(i, N, c_old.g, c_new.g),
                        smooth_step(i, N, c_old.b, c_new.b));
}

void shift_color_all(uint32_t old_color, uint32_t new_color) {
    ANIMATE(i, ANIMATION_TIME_MS) {
        uint32_t shifted = shift_color(i, ANIMATION_TIME_MS, old_color, new_color);

        IT.paint(shifted);
        IS.paint(shifted);
        pixels.setPixelColor(seconds_led, shifted);
        minute_led.paint(shifted);
        hour_led.paint(shifted);
        oclock_led.paint(shifted);

        pixels.show();
        delay_short();
    }
}

void tick() {
    time = rtc.now();
}

inline void save_last_leds() {
    last_second_led = seconds_led;
    last_minute_led = minute_led;
    last_hour_led = hour_led;
    last_oclock_led = oclock_led;
}

void calculate_next_leds() {
    uint8_t hour = time.hour();
    uint8_t min = time.minute();
    uint8_t sec = time.second();

    seconds_led = static_cast<uint8_t>(sec % N_SECONDS_LED + 1);

    if(min < 5) {                   /// 0 - 5
        oclock_led = O_OCLOCK;
        minute_led = M_NONE;
    } else if(min < 35) {           /// 5 - 35
        oclock_led = O_PAST;
        if(min < 10)                // 5 - 10
            minute_led = M_5;
        else if(min < 15)           // 10 - 15
            minute_led = M_10;
        else if(min < 20)           // 15 - 20
            minute_led = M_15;
        else if(min < 25)           // 20 - 25
            minute_led = M_20;
        else if(min < 30)           // 25 - 30
            minute_led = M_25;
        else                        // 30 - 35
            minute_led = M_30;
    } else {                        /// 35 - 60
        hour = static_cast<uint8_t>(hour + 1);
        oclock_led = O_TO;
        if(min < 40)                // 35 - 40
            minute_led = M_25;
        else if(min < 45)           // 40 - 45
            minute_led = M_20;
        else if(min < 50)           // 45 - 50
            minute_led = M_15;
        else if(min < 55)           // 50 - 55
            minute_led = M_10;
        else                        // 55 - 60
            minute_led = M_5;
    }

    while(hour >= 12)
        hour -= 12;
    hour_led = H[hour];
}

void display_time() {
    bool no_led_changed = true;
    uint32_t color = current_color();
    ANIMATE(i, ANIMATION_TIME_MS) {
        uint32_t to_black = shift_color(i, ANIMATION_TIME_MS, color, COLOR_BLACK);
        uint32_t to_color = shift_color(i, ANIMATION_TIME_MS, COLOR_BLACK, color);

        if(last_second_led != seconds_led) {
            pixels.setPixelColor(last_second_led, to_black);
            pixels.setPixelColor(seconds_led, to_color);
            no_led_changed = false;
        }
        if(last_minute_led != minute_led) {
            if(last_minute_led == M_20 && minute_led == M_25)
                M_5.paint(to_color);
            else if(last_minute_led == M_25 && minute_led == M_20)
                M_5.paint(to_black);
            else {
                last_minute_led.paint(to_black);
                minute_led.paint(to_color);
            }
            no_led_changed = false;
        }
        if(last_hour_led != hour_led) {
            last_hour_led.paint(to_black);
            hour_led.paint(to_color);
            no_led_changed = false;
        }
        if(last_oclock_led != oclock_led) {
            last_oclock_led.paint(to_black);
            oclock_led.paint(to_color);
            no_led_changed = false;
        }

        if(no_led_changed)
            break;

        pixels.show();
        delay_short();
    }
}

/// Birthday class is for playing "Happy Birthday To You" song
/// and displaying a huge red heart on the board.
class Birthday {
    /// Shifts between the \c old_color to \c new_color but only affets heart leds.
    /// \param old_color Color to shift from.
    /// \param new_color Color to shift to.
    /// \param dly Delay after the shifting in millis.
    static void shift_color_heart(uint32_t old_color, uint32_t new_color, uint16_t dly) {
        uint8_t heart[] = {11, 21, 23, 31, 35, 41, 47, 51, 59, 61, 71,
                           72, 77, 82, 84, 87, 89, 92, 96, 97, 101, 102};

        ANIMATE(i, ANIMATION_TIME_MS) {
            uint32_t shift = shift_color(i, ANIMATION_TIME_MS, old_color, new_color);
            for(uint8_t h_l = 0; h_l < 22; ++h_l)
                pixels.setPixelColor(heart[h_l], shift);
            pixels.show();
            delay_short();
        }
        delay(dly);
    }

    /// Checks whether birthday mode is cancelled or not.
    /// \return \c true if birthday mode is cancelled, \c false otherwise.
    static bool cancel() {
        if(cancelled) {
            begun = false;
            cancelled = false;
            return true;
        }
        return false;
    }

public:
    static bool begun;
    static volatile bool cancelled;
    static volatile bool manual_begin;

    /// Sets up the birthday mode. Should be called on \c setup().
    static void begin() {
        begun = false;
        cancelled = false;
        manual_begin = false;
        pinMode(PIN_SPEAKER, OUTPUT);
    }

    /// Checks if birthday mode should be activated now.
    /// \return \c true if birthday mode is manually activated or
    /// the date is 12/05 and time is 9 am, 1 pm or 6 pm, \c false otherwise.
    static bool is_today() {
        return manual_begin || (time.day() == 6 && time.month() == 12
                                && (time.hour() == 6 || time.hour() == 13 || time.hour() == 21)
                                && time.minute() == 0 && time.second() == 0);
    }

    /// Begins the birthday mode. Changes the board schema to a big heart and plays "Happy Birthday To You" song.
    /// <br><br> Birthday mode lasts 3 hour.
    static void celebrate() {
        begun = true;
        shift_color_all(current_color(), COLOR_BLACK);
        shift_color_heart(COLOR_BLACK, COLOR_RED, 500);
        play_happy_birthday();
        for(uint16_t i = 0; i < 10800; ++i) {
            delay_short();
            if(cancel()) break;
        }
        shift_color_heart(COLOR_RED, COLOR_BLACK, 0);
        manual_begin = false;
        begun = false;
    }
};

bool Birthday::begun;
volatile bool Birthday::cancelled;
volatile bool Birthday::manual_begin;

void add_time(TimeSpan ts) {
	rtc.adjust(time + ts);
	tick();
}

void on_color_button_pressed() {
    uint32_t old_color = current_color();

    led_color_idx = static_cast<uint8_t>((led_color_idx + 1) % N_COLORS);
    EEPROM.update(ADDRESS_EEPROM_COLOR, led_color_idx);

    shift_color_all(old_color, current_color());
}

void on_color_button_double_pressed() {
    if(!Birthday::begun)
        Birthday::manual_begin = true;
}

void on_time_button_pressed() {
	add_time(ONE_MIN);
}

void on_time_button_double_pressed() {
    add_time(ONE_HOUR);
}

void color_isr() {
    if(Birthday::begun && !Birthday::cancelled)
        Birthday::cancelled = true;
    else
        COLOR_BUTTON->update();
}

void time_isr() {
    if(Birthday::begun && !Birthday::cancelled)
        Birthday::cancelled = true;
    else
        TIME_BUTTON->update();
}

bool is_night() {
    return time.hour() >= 21 || time.hour() < 7;
}

void adjust_brightness() {
    uint8_t old_brightness = EEPROM.read(ADDRESS_EEPROM_BRIGHTN);
    uint32_t old_color = current_color();

    if(is_night())
        brightness = BRIGHTNESS_LOW;
    else
        brightness = BRIGHTNESS_HIGH;
    EEPROM.update(ADDRESS_EEPROM_BRIGHTN, brightness);

    if(old_brightness != brightness)
        shift_color_all(old_color, current_color());
}

void setup() {
    rtc.begin();
    pixels.begin();
    Birthday::begin();

    pixels.show();

    COLOR_BUTTON = new Button(PIN_COLOR_BUTTON, color_isr, on_color_button_pressed, on_color_button_double_pressed);
    TIME_BUTTON = new Button(PIN_TIME_BUTTON, time_isr, on_time_button_pressed, on_time_button_double_pressed);

    led_color_idx = EEPROM.read(ADDRESS_EEPROM_COLOR);
    if(led_color_idx > (N_COLORS - 1))
        led_color_idx = 0;

    tick();
	
#ifdef FIRST_TIME_RUN
    rtc.adjust(DateTime(F(__DATE__), F(__TIME__)));
	rtc.writeSqwPinMode(SquareWave32kHz);
#endif

    brightness = EEPROM.read(ADDRESS_EEPROM_BRIGHTN);
    if(brightness != BRIGHTNESS_LOW || brightness != BRIGHTNESS_HIGH)
        brightness = BRIGHTNESS_HIGH;
    if(is_night())
        brightness = BRIGHTNESS_LOW;

    calculate_next_leds();
    shift_color_all(COLOR_BLACK, current_color());
}

void loop() {
    tick();

    if(Birthday::is_today()) {
        Birthday::celebrate();
        tick();
        calculate_next_leds();
        shift_color_all(COLOR_BLACK, current_color());
        return;
    }

    save_last_leds();
    calculate_next_leds();
    display_time();

    COLOR_BUTTON->perform_clicks();
    TIME_BUTTON->perform_clicks();

    adjust_brightness();
}

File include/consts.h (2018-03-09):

#ifndef WORDCLOCK_CONSTS_H
#define WORDCLOCK_CONSTS_H

#include "Arduino.h"

#define ZERO                    (uint8_t)(0x00)     // workaround for issue #527
#define UNUSED_LED_FOR_25       89

#define ADDRESS_DS1307          0x68
#define ADDRESS_EEPROM_COLOR    0x0
#define ADDRESS_EEPROM_BRIGHTN  0x4
#define PIN_TIME_BUTTON         PIN3    // FIXME time 2
#define PIN_COLOR_BUTTON        PIN2    // FIXME color 3?
#define PIN_NEOPIXELS           PIN4
#define PIN_SPEAKER             PIN7

#define N_PIXELS                116
#define N_COLORS                7
#define N_SECONDS_LED           5

#define COLOR_BLACK             (uint32_t) 0x000000
#define COLOR_RED               (uint32_t) 0xFF0000

#define BRIGHTNESS_LOW          0x20    // 0.125
#define BRIGHTNESS_HIGH         0xFF    // 1.000

#define BTN_DEBOUNCE_THRESHOLD  50
#define BTN_CLICK_THRESHOLD     300

#define ANIMATION_TIME_MS       200
#define ANIMATE(i, duration)    for(uint8_t (i) = 0; (i) <= (duration); (i)++)
#define SMOOTH_STEP(x)          ((x) * (x) * (3 - 2 * (x)))

#define NOTE_G                  1275
#define NOTE_A                  1136
#define NOTE_B                  1014
#define NOTE_c                  956
#define NOTE_d                  834
#define NOTE_e                  765
#define NOTE_x                  655
#define NOTE_y                  715
#define NOTE_REST               0

#define SONG_TEMPO              175
#define SPEE                    5

typedef struct {
    uint8_t r;
    uint8_t g;
    uint8_t b;
} color;

#endif //WORDCLOCK_CONSTS_H

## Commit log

2018-01-31 refactor led enabling disabling
2018-01-31 move all leds by 1
2018-02-01 fix 20->25 and 25->20 minute transitions
    [wordclock.ino]
2018-02-01 - make sure the pixels fade-in when program starts. - change delay() functions with counters in time button and color button - pixels now fade in and out when color button is pressed
2018-02-02 make allowed delays united, so time change can occur automatically in loop(). also fix button timers not updating
    [wordclock.ino]
2018-02-02 separate allowed times for color and time buttons, again
2018-02-03 remove time constraints on buttons because external interrupts are not available by default
2018-02-05 - function and #define location changes - refactor calculation of minutes - skip current iteration of loop() if no led has been changed since the last iteration - fix when O_OCLOCK is on, M_5 would a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
    [wordclock.ino]
2018-02-05 Revert "implement night mode to work between h22-h8"
    This reverts commit 2964def
    [wordclock.ino]
2018-02-06 - use OneButton lib - change struct time_s with class Time - rename class led to class LedArray
2018-02-06 replace OneButton lib with custom impl
    [wordclock.ino]
2018-02-06 rename some enum values in Button
2018-02-07 fix perform_clicks() won't check for click events if button state machine in PRESSED or RELEASED
    [wordclock.ino]
2018-02-07 fix set_pixel_brightness calculates smooth_step with 255 instead of MAX_BRIGHTNESS
    [wordclock.ino]
2018-02-07 zero = 0x0 probably wouldn't disable and enable oscillator, make it zero = (byte)0x00
    [wordclock.ino]
2018-02-07 - more refactor - remove unnecessary call to Wire.write()
2018-02-08 - keep track of date as well as time - fix some time read masks - move hour overflow check in on_t_b_pressed() inside of min overflow check
    [wordclock.ino]
2018-02-08 implement birthday mode and hope no bugs are present
    [wordclock.ino]
2018-02-09 fix time change animation after celebration is over
    [wordclock.ino]
2018-02-10 check if celebration is already cancelled when time button is pressed
2018-02-10 Revert "remove Birthday::begin()"
    This reverts commit 6e99953
    [wordclock.ino]
2018-02-10 fix minute_led is initialized to M_5 instead of M_NONE
    [wordclock.ino]
2018-02-12 refactor color shifting so we can shift one color to another easily when color button is pressed
2018-02-12 implement current_color() instead of array access
2018-02-12 fix seconds_led is incorrectly initialized to zero instead of one since we changed the algorithm to compute the led index
    [wordclock.ino]
2018-02-12 - fix typo in name of dec2bcd - fix bcd2dec does not cast the whole computation
    [wordclock.ino]
2018-02-13 - change the signature of shift_color_heart() - implement double-click color button manually triggers birthday mode
2018-02-13 color button now also disables birthday mode
2018-03-01 implement long pressing to button lib
2018-03-01 Revert "implement long pressing to button lib"
    This reverts commit 53eb45d
    [consts.h, wordclock.ino]
2018-03-09 change speaker pin to pin7
2018-03-09 remove claret as it is impossible to light with leds
2018-03-15 move manual_begin to the beginning of the check, so is_today() won't check for time if manual_begin triggered
    [wordclock.ino]
2018-03-16 fix after a brightness change, leds won't shift to their new states gracefully
    [wordclock.ino]
2018-03-16 add function prototypes to consts.h and rename it to wordclock.h
2018-03-16 fix smooth_step shifts from new to old instead of vice versa
    [wordclock.ino]
2018-03-20 fix interrupts() are not called if no button is pressed
    [wordclock.ino]
2018-03-20 fix very upper part of the heart not lit
    [wordclock.ino]
2018-03-20 fix time and color button pins are needs to change
    [wordclock.h]
2018-03-21 make led array range upper bound exclusive (this fixes led0 being lit)
    [wordclock.ino]
2018-03-21 - code style changes - wait for 950ms instead of 1000ms while waiting for birthday mode to finish - use tick() to avoid code duplication
    [wordclock.ino]
2018-03-21 fix brightness assignment is incorrect
    [wordclock.ino]
2018-03-22 change the pin numbers of the buttons because i'm an idiot and burnt the color button while soldering
    [wordclock.h]
2018-04-05 make animation time 100ms as it is a necessary thing to do in order to prevent second skipping
    [wordclock.h]
2018-04-05 fix initial brightness is calculated incorrectly
    [wordclock.ino]
2018-04-05 fix indentation of the array initializers
    [wordclock.ino]
2018-04-05 - rename wordclock.h to wordclock.hpp - missing cast in wordclock.hpp
    [wordclock.hpp, wordclock.ino]
2018-05-31 - separate Button and LedArray classes to their own files - move docs to header files - reformat code
2018-06-13 keep track of drag minutes and increment the time by one min every month
2018-10-01 add additional resources to build the clock
    [schematic_1.3.brd, schematic_1.3.sch, slat_output.dxf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]
2018-10-08 fix 'accuracy fix' does not actually fixed the problem
    [wordclock.hpp, wordclock.ino]
2018-11-18 rearrange hours since clock gives the wrong hour shown
    [wordclock.ino]

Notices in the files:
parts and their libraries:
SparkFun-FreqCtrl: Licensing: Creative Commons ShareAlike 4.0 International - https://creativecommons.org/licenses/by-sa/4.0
